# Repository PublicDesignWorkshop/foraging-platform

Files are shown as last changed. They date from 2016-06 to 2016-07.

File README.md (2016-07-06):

#Foraging platform

Installation

This repository contains the software and hardware designs to produce a low-power datalogger for remote monitoring fruit ripeness. Included in this repository is:

1. Arduino code for the datalogger itself
2. schematics and PCB designs for custom, low-power arduino variants in  Eagle and Gerber format
3. Enclosure models in sketchup and .STL format for 3D printing
4. PDF of lids to fit the enclosures that can be laser-cut

###Goals
This platform is meant to be deployed autonomously on fruit trees while their fruit ripens. It offers a way for urban foragers to monitor remotely many trees, and lessen their reliance on volunteers or manually checking the fruit status on trees across large distances over long durations. It uses two different kinds of sensors to monitor the fruit’s ripeness. The first is a bend sensor attached to a branch that will bear fruit to represent the ripeness of the tree. In the second, a stretch sensor is placed between two branches. In each case, as the fruit grows, the branch bearing that fruit bends, providing a changing reading to our sensors.

###Current Iteration
Right now, the platform uses a real-time clock module to wake a custom Arduino board from a deep, energy-saving sleep mode and then logs the current bend data to a MicroSD card. In this configuration, the board has lasted over a month deployed in a tree during Summer 2015, reading every 12 hours. Decreasing the frequency of readings should enable much longer deployment times. Currently (Summer 2016) we are testing new sensors reading every 23 hours.

###Photos







###Technical Details
[Bill of Materials](https://docs.google.com/spreadsheets/d/1Vs3_GVGOHFVuYa3o1AHFbKYVgtYUHnmqFQ5do5olbm8/edit#gid=990807043) - includes notes for datalogging, WiFi and cellular versions

####Hardware and software dependencies

Hardware:

* [SparkFun DeadOn RTC Breakout - DS3234](https://www.sparkfun.com/products/10160)
* [LC Tech Mini SD Card Module](http://www.chinalctech.com/index.php?_m=mod_product&_a=view&p_id=646)

Software Libraries:

* [SD Library](https://www.arduino.cc/en/Reference/SD)
* [ManiacBug's fork of RTClib](https://github.com/maniacbug/RTClib)
* [Rodan's DS3234 Library](https://github.com/rodan/ds3234)
* [Enerlib](http://playground.arduino.cc/Code/Enerlib)

####Potential future comm/sensor choices
Cell phone breakout board and pay-as-you-go SIM card options:

* https://www.adafruit.com/products/1963
* https://www.adafruit.com/products/1946

Inexpensive WiFi breakout board:

* https://www.sparkfun.com/products/13678

21 Sensors under $2:

* http://randomnerdtutorials.com/21-arduino-modules-you-can-buy-for-less-than-2/

###Problems and Issues
#####Accuracy Issues
There are a couple of obvious issues with this setup. The first is that the weight of fruit is the proxy for ripeness. This is not as much of a problem as it could be, because knowing when fruit gets heavy means that volunteer resources could be used to check on it for more detailed results. Additionally, we are experimenting with combinations of gas sensors to more properly detect ripeness itself.
#####Technical Issues
By far the most limiting issues we’ve come across have been technical. Detecting a bend is not very difficult, and building out a low-power sensor board as well as the industrial design planning to deploy the platform has been relatively straightforward. However, the initial vision of a wireless, long-term deployment has been difficult. Even sensing and sending bend every 24 hours doesn’t come very close to the long-term deployment envisioned.

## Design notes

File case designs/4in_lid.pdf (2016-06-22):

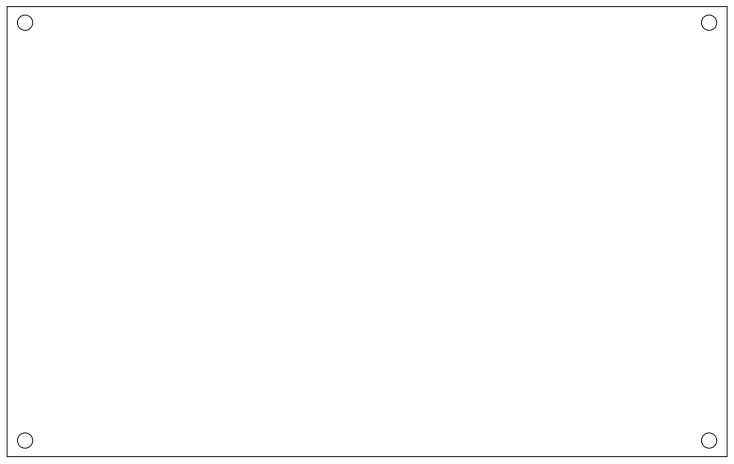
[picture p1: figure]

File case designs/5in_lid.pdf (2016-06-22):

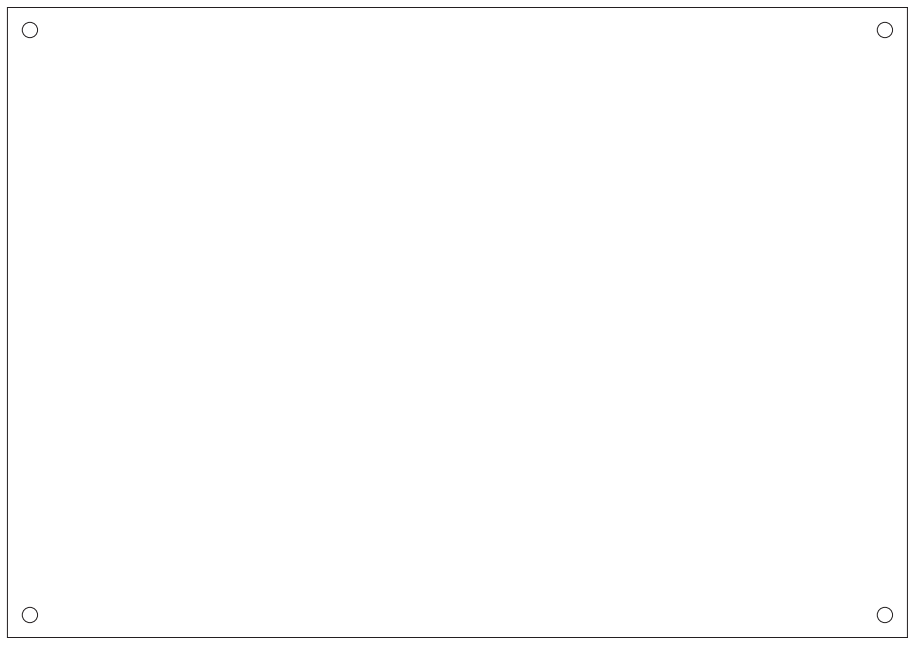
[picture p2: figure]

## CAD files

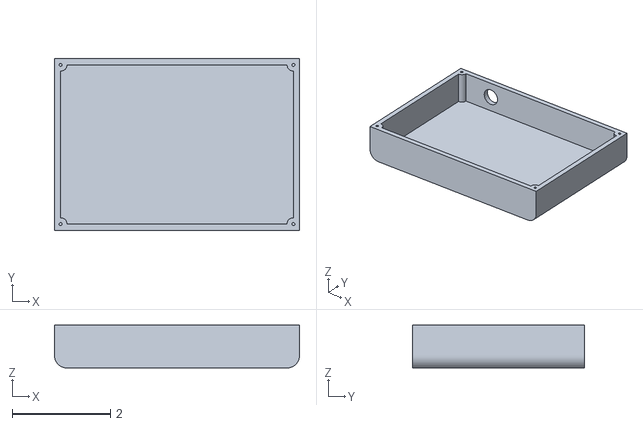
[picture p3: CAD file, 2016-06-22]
case designs/5in_box.stl
5.00 x 3.50 x 0.875

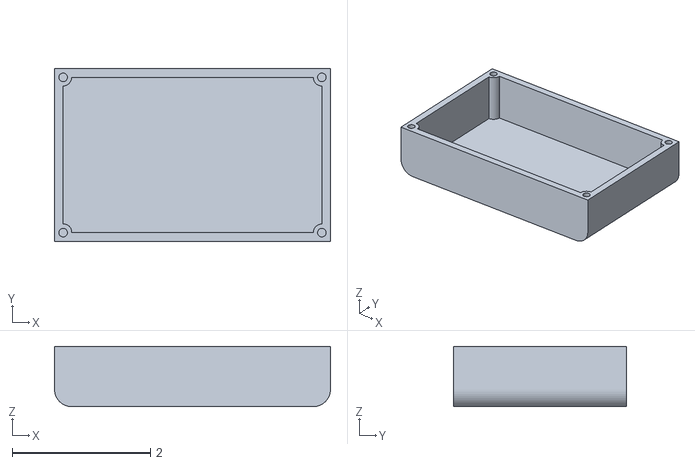
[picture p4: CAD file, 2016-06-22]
case designs/4in_box.stl
4.00 x 2.50 x 0.875

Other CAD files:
case designs/4in_box.skp
case designs/4in_box~.skp
case designs/5in_box.skp
case designs/5in_box~.skp

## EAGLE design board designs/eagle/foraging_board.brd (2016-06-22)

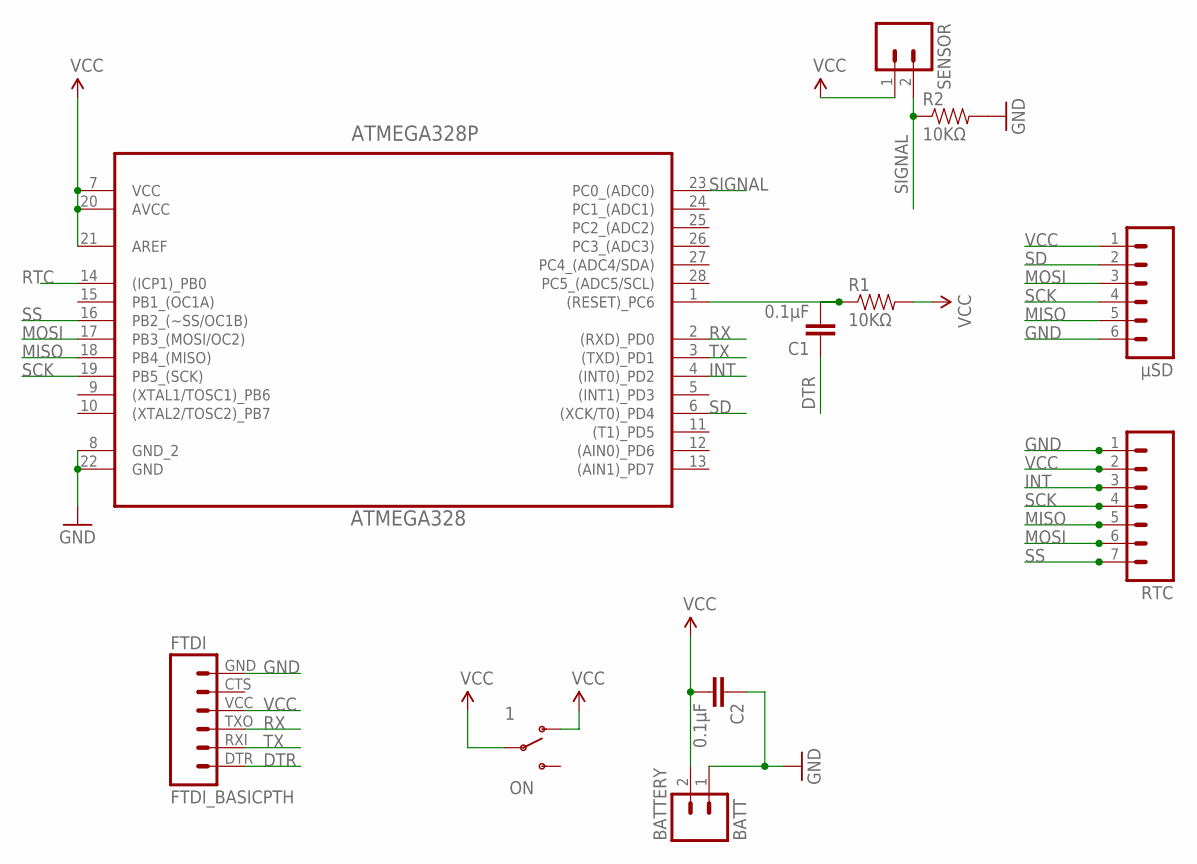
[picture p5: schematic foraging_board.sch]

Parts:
ATMEGA328P: ATMEGA328; DIP254P762X457-28
BATTERY: BATT; JST-2-PTH-NS
C1, C2: 0.1µF; CAP-PTH-SMALL-KIT
FTDI: FTDI_BASICPTH; FTDI_BASIC
ON: 1; SWITCH-SPDT_KIT
R1, R2: 10KΩ; AXIAL-0.3EZ
RTC: M07LONGPADS; 1X07_LONGPADS
SENSOR: M02PTH; 1X02
µSD: M06LONGPADS; 1X06_LONGPADS

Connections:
DTR: C1.1, FTDI.DTR (1)
GND: ATMEGA328P.8 (GND_2), ATMEGA328P.22 (GND), BATTERY.1, C2.1, FTDI.GND (6), R2.P$2 (2), RTC.1, µSD.6
INT: ATMEGA328P.4 ((INT0)_PD2), RTC.3
MISO: ATMEGA328P.18 (PB4_(MISO)), RTC.5, µSD.5
MOSI: ATMEGA328P.17 (PB3_(MOSI/OC2)), RTC.6, µSD.3
unnamed: ATMEGA328P.1 ((RESET)_PC6), C1.2, R1.P$1 (1)
RTC: ATMEGA328P.14 ((ICP1)_PB0)
RX: ATMEGA328P.2 ((RXD)_PD0), FTDI.TXO (3)
SCK: ATMEGA328P.19 (PB5_(SCK)), RTC.4, µSD.4
SD: ATMEGA328P.6 ((XCK/T0)_PD4), µSD.2
SIGNAL: ATMEGA328P.23 (PC0_(ADC0)), R2.P$1 (1), SENSOR.2
SS: ATMEGA328P.16 (PB2_(~SS/OC1B)), RTC.7
TX: ATMEGA328P.3 ((TXD)_PD1), FTDI.RXI (2)
VCC: ATMEGA328P.7 (VCC), ATMEGA328P.20 (AVCC), ATMEGA328P.21 (AREF), BATTERY.2, C2.2, FTDI.VCC (4), ON.1 (O), ON.2, R1.P$2 (2), RTC.2, SENSOR.1, µSD.1

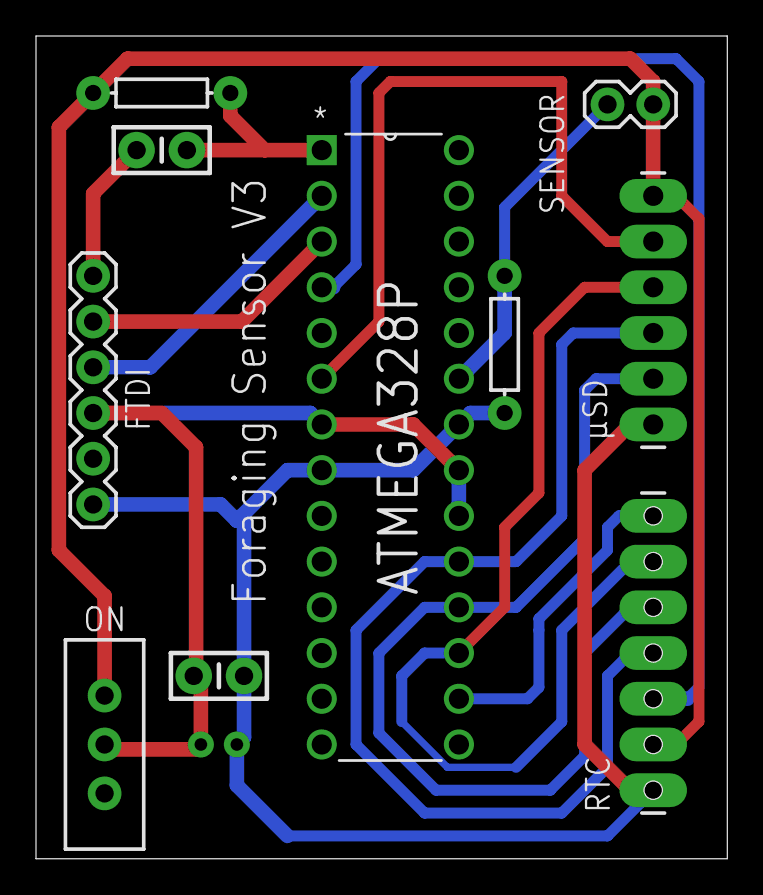
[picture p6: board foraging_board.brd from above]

Board: 2 copper layers, 38.4 x 45.7 mm, 11 parts (0 on the bottom side), 13 nets.

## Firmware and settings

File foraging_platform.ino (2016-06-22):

#include <SPI.h>
#include <SD.h>           //For SD
#include <Wire.h>
#include <RTClib.h>       //For RTC
#include <RTC_DS3234.h>
#include "Enerlib.h"      //For Power management

#define BUFF_MAX 256

const int chipSelect = 4;

const int timePin = 10;    // RTC select pin
RTC_DS3234 RTC(timePin); 

uint8_t sleep_hour = 23;   // the sleep interval in hours between 2 consecutive alarms
//uint8_t sleep_minute = ;
//uint8_t sleep_day = ;

Energy energy;
int time_interrupt=0;

//////////////////////////////////////////////////////
////FUNCTIONS FROM OTHER RTC LIBRARY TO CLEAN UP
// control register bits
#define DS3234_A1IE     0x1
#define DS3234_A2IE     0x2
#define DS3234_INTCN    0x4

// status register bits
#define DS3234_A1F      0x1
#define DS3234_A2F      0x2
#define DS3234_OSF      0x80

uint8_t dectobcd(const uint8_t val){
    return ((val / 10 * 16) + (val % 10));
}

void DS3234_set_addr(const uint8_t pin, const uint8_t addr, const uint8_t val){
    digitalWrite(pin, LOW);
    SPI.transfer(addr);
    SPI.transfer(val);
    digitalWrite(pin, HIGH);
}

uint8_t DS3234_get_addr(const uint8_t pin, const uint8_t addr){
    uint8_t rv;

    digitalWrite(pin, LOW);
    SPI.transfer(addr);
    rv = SPI.transfer(0x00);
    digitalWrite(pin, HIGH);
    return rv;
}

void DS3234_set_creg(const uint8_t pin, const uint8_t val){
    DS3234_set_addr(pin, 0x8E, val);
}

void DS3234_set_a2(const uint8_t pin, const uint8_t mi, const uint8_t h, const uint8_t d,
                   const uint8_t * flags){
    uint8_t t[3] = { mi, h, d };
    uint8_t i;

    for (i = 0; i <= 2; i++) {
        digitalWrite(pin, LOW);
        SPI.transfer(i + 0x8B);
        if (i == 2) {
            SPI.transfer(dectobcd(t[2]) | (flags[2] << 7) | (flags[3] << 6));
        } else
            SPI.transfer(dectobcd(t[i]) | (flags[i] << 7));
        digitalWrite(pin, HIGH);
    }
}

void DS3234_set_sreg(const uint8_t pin, const uint8_t sreg){
    DS3234_set_addr(pin, 0x8F, sreg);
}

uint8_t DS3234_get_sreg(const uint8_t pin){
    uint8_t rv;
    rv = DS3234_get_addr(pin, 0x0f);
    return rv;
}

void DS3234_clear_a2f(const uint8_t pin){
    uint8_t reg_val;

    reg_val = DS3234_get_sreg(pin) & ~DS3234_A2F;
    DS3234_set_sreg(pin, reg_val);
}

// END WEIRD FUNCTION DUMP
//////////////////////////////////////////////////////

void set_next_alarm(void){
    DateTime now = RTC.now();
    unsigned char wakeup_min;
    unsigned char wakeup_hour;
    
    // calculate the minute when the next alarm will be triggered
    wakeup_min = now.minute();

    //calculate the hour when the next alarm will be triggered
    wakeup_hour = now.hour() + sleep_hour;
    if (wakeup_hour > 23) {
        wakeup_hour -= 24;
    }

    // flags define what calendar component to be checked against the current time in order
    // to trigger the alarm
    // A2M2 (minutes) (0 to enable, 1 to disable)
    // A2M3 (hour)    (0 to enable, 1 to disable) 
    // A2M4 (day)     (0 to enable, 1 to disable)
    // DY/DT          (dayofweek == 1/dayofmonth == 0)
    uint8_t flags[4] = { 0, 0, 1, 1 };

    // set Alarm2. only the minute is set since we ignore the hour and day component
    DS3234_set_a2(timePin, wakeup_min, wakeup_hour, 0, flags);

    // activate Alarm2
    DS3234_set_creg(timePin, DS3234_INTCN | DS3234_A2IE);  
}

void INT0_ISR(void){
  //detach interrupt and set time_interrupt=1
  //interrupt must be attached again
  detachInterrupt(0);
  time_interrupt=1;
}

void logSensorReading() {
    // make a string for assembling the data to log:
  String dataString = "";
  
  // get current date/time and append to string
  const int len = 32;
  static char buf[len];

  DateTime now = RTC.now();
  dataString += now.toString(buf,len);

  // read three sensors and append to the string:
  int analogPin = 0;
  int sensor = analogRead(analogPin);
  dataString += ", "+String(sensor);

  // open the file. note that only one file can be open at a time,
  // so you have to close this one before opening another.
  File dataFile = SD.open("datalog.txt", FILE_WRITE);

  // if the file is available, write to it:
  if (dataFile) {
    dataFile.println(dataString);
    dataFile.close();
    // print to the serial port too:
    Serial.println(dataString);
  }
  // if the file isn't open, pop up an error:
  else {
    Serial.println("error opening datalog.txt");
  }
}

void setup(){
    Serial.begin(9600);
    Serial.println("Entering setup");

    SPI.begin();
    RTC.begin();
    
    if (! RTC.isrunning()) {
      Serial.println("RTC is NOT running!");
      return;
    } else {
      Serial.print("Setting time to... ");
      Serial.print(__DATE__);
      Serial.print(' ');
      Serial.println(__TIME__);
      // following line sets the RTC to the date & time this sketch was compiled
      RTC.adjust(DateTime(__DATE__, __TIME__));
    }
    
    Serial.print("Initializing SD card...");
    // see if the card is present and can be initialized:
    if (!SD.begin(chipSelect)) {
      Serial.println("Card failed, or not present");
      // don't do anything more:
      return;
    }
    Serial.println("card initialized.");

    pinMode(2, INPUT);
    delay(5000);

    DS3234_clear_a2f(timePin);
    set_next_alarm();
    attachInterrupt(0, INT0_ISR, LOW);
}

void loop(){
  if(time_interrupt==1){
    Serial.println(" time_interrupt==1");
    time_interrupt=0;
    
    // set next alarm
    set_next_alarm();
    // clear a2 alarm flag and let INT go into hi-z
    DS3234_clear_a2f(timePin);
    //Attach interrupt again
    attachInterrupt(0, INT0_ISR, LOW);
    
    if (energy.WasSleeping()){
        Serial.println("  Interrupt and was sleeping");
        logSensorReading();
    }
    else
    {
        /*
        The IRQ happened in awake state.
        This code is for the "normal" ISR.
        */
        Serial.println("  Interrupt and was NOT sleeping");
    }
  }
  Serial.println("Entering loop");
  delay(1000);

  Serial.println("Powering down");
  energy.PowerDown();
}

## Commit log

2016-06-22 First commit: arduino file, Eagle and gerber PCB and schematic files, and casing designs
    [boxes.skp, boxes.stl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]
2016-06-22 break out cases so no single file has two sizes
    [4in_box.skp, 4in_box.stl, 5in_box.skp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]
2016-07-05 New case design files, updated README
    [4in_box.skp, 4in_box~.skp, 5in_box.skp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]
2017-04-04 Adding data from 2015 and 2016 deployments
    [BEND_DATALOG.CSV, DATALOG.csv, STRETCH_DATALOG.CSV]

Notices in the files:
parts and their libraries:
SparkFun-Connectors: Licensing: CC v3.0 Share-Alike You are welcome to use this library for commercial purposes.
